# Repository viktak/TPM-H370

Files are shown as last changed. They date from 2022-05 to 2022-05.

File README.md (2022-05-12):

# TPM-H370
TPM 2.0 Module for Gigabyte H370 series motherboards

**WARNING:**
The schematics are correct, tested.
The PCB layout is updated to use the correct connector (v1.1), should be correct, but it is not tested in production!

Further details: https://diy.viktak.com/2022/04/home-made-tpm2-0-module.html.

## License

[Attribution 4.0 International](https://creativecommons.org/licenses/by/4.0/)

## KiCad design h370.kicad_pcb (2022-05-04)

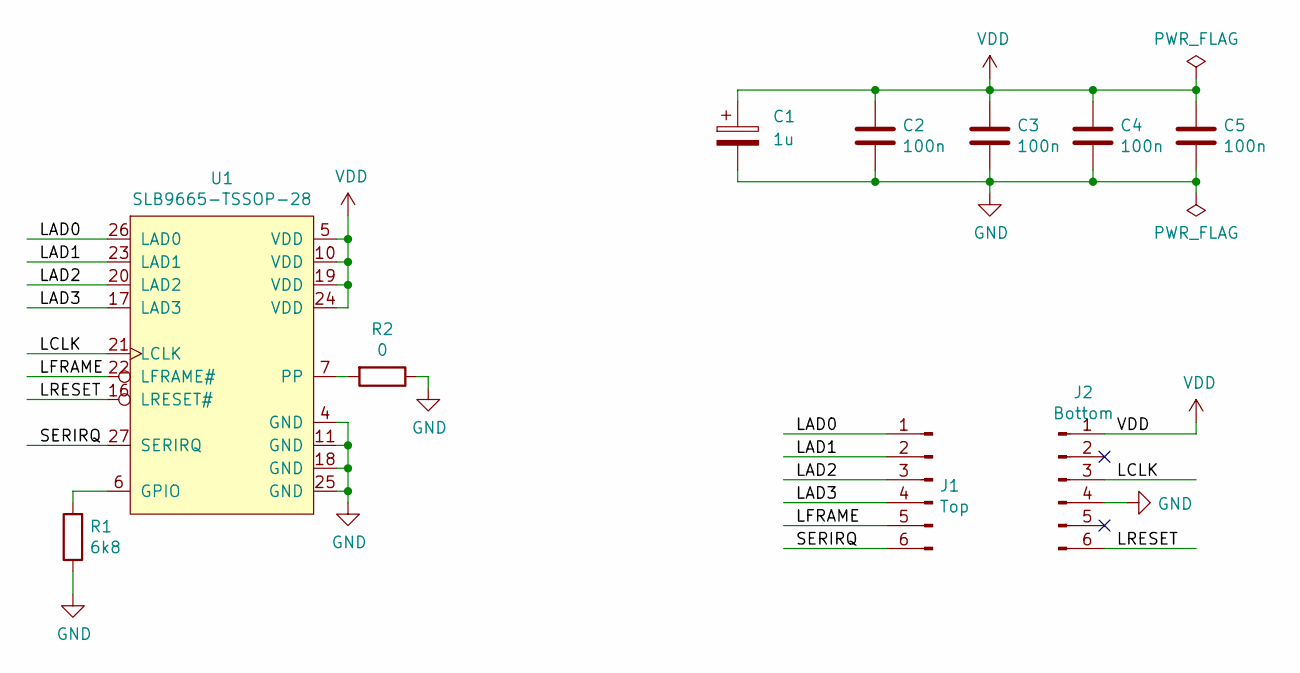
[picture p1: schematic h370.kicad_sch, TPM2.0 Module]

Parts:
C1: 1u; CP_EIA-3216-10_Kemet-I
C2, C3, C4, C5: 100n; C_1206_3216Metric
J1: Top; Solder pad connector - 6 pin - 2.0 pitch
J2: Bottom; Solder pad connector - 6 pin - 2.0 pitch
R1: 6k8; R_0805_2012Metric
R2: 0; R_0805_2012Metric
U1: SLB9665-TSSOP-28; TSSOP-28_4.4x9.7mm_P0.65mm

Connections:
/LAD0: J1.1, U1.26 (LAD0)
/LAD1: J1.2, U1.23 (LAD1)
/LAD2: J1.3, U1.20 (LAD2)
/LAD3: J1.4, U1.17 (LAD3)
/LCLK: J2.3, U1.21 (LCLK)
/LFRAME: J1.5, U1.22 (LFRAME#)
/LRESET: J2.6, U1.16 (LRESET#)
/SERIRQ: J1.6, U1.27 (SERIRQ)
GND: C1.2, C2.2, C3.2, C4.2, C5.2, J2.4, R1.1, R2.1, U1.4 (GND), U1.11 (GND), U1.18 (GND), U1.25 (GND)
unnamed: R1.2, U1.6 (GPIO)
unnamed: R2.2, U1.7 (PP)
VDD: C1.1, C2.1, C3.1, C4.1, C5.1, J2.1, U1.5 (VDD), U1.10 (VDD), U1.19 (VDD), U1.24 (VDD)

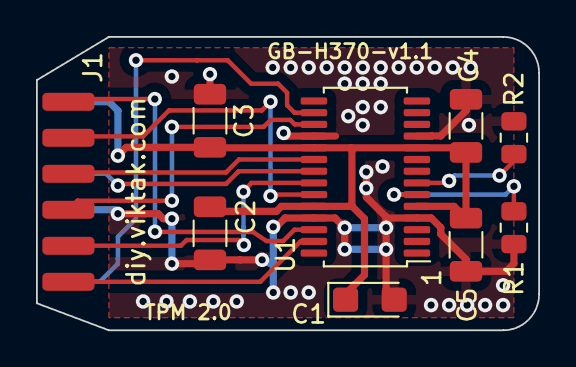
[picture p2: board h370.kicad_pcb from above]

Board: 2 copper layers, 27.9 x 16.3 mm, 10 parts (1 on the bottom side), 12 nets.
